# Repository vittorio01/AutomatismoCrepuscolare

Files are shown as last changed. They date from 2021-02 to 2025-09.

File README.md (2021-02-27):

# AutomatismoCrepuscolare
Un automatismo crepuscolare programmabile e intelligente che può essere applicato in molti campi

La scheda funziona con un semplice arduino pro mini.

In questa pagina è presente, oltre a uno schema elettrico del circuito principale e il programma per l'atmega328, anche una guida per l'utilizzo e la costruzione.
Per chi volesse costruire la scheda elettronica, sul file bottom.pdf è predente la faccia inferiore (l'unica) gia pronta per essere utilizzata (da notare che vanno mssi anche due ponticelli.

Questo progetto è ancora in fase sperimentale, quindi c'è la possibilità che non funzioni correttamente.

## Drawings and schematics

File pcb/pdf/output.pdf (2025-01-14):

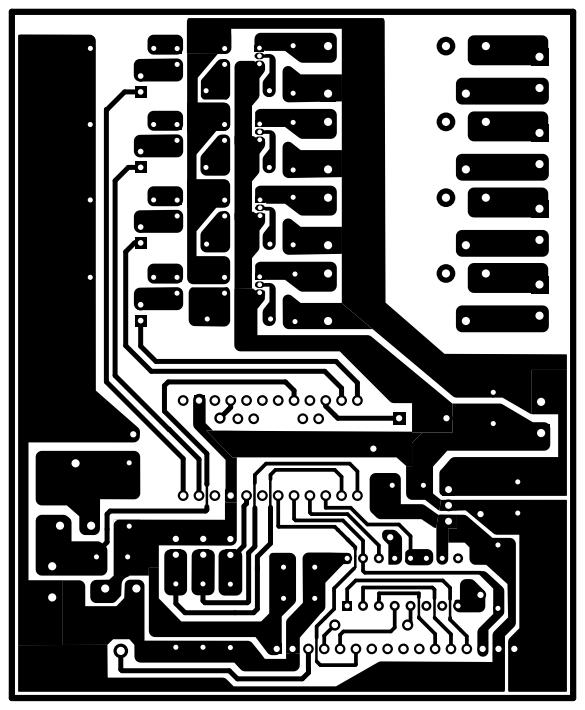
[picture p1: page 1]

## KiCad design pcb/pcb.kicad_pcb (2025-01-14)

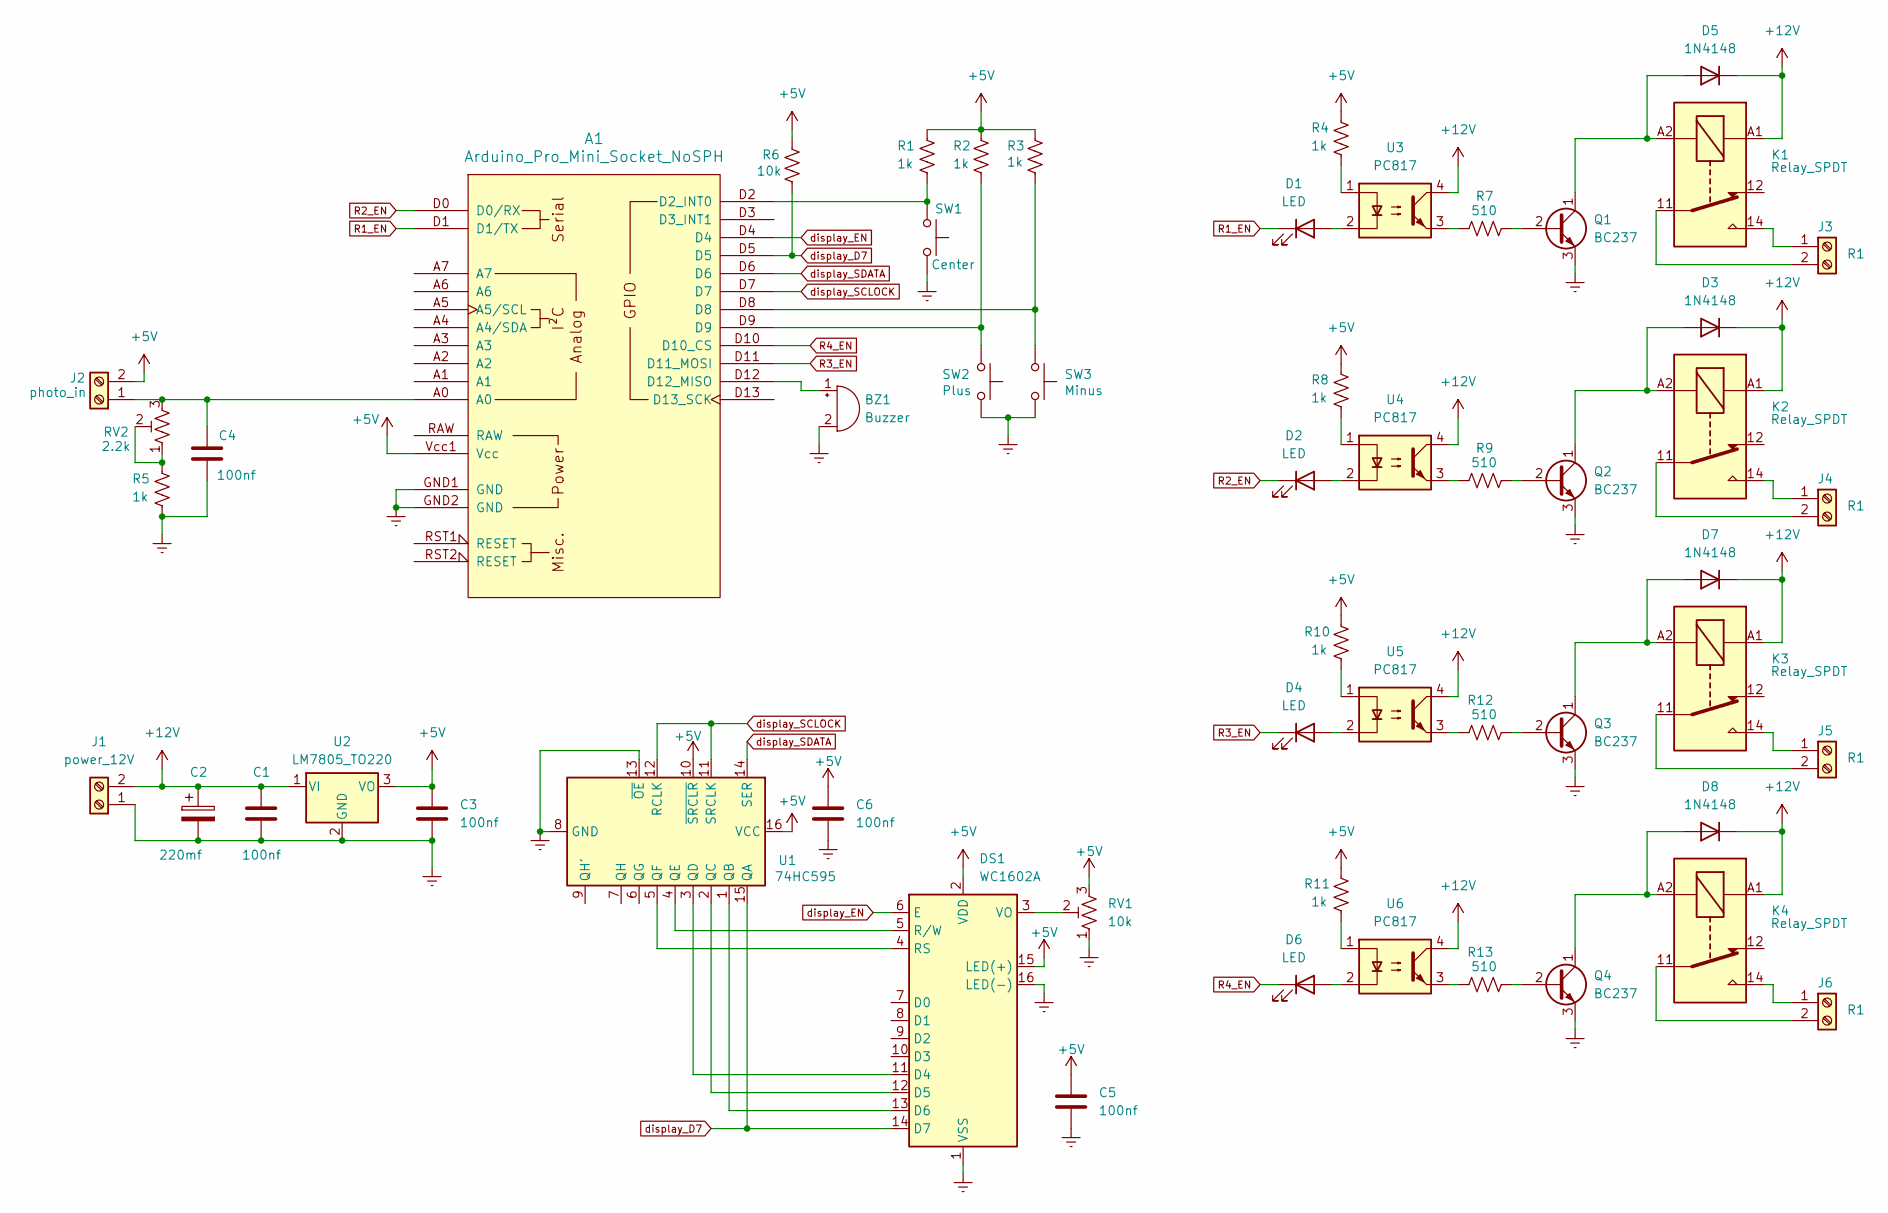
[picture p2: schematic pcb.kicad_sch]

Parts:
A1: Arduino_Pro_Mini_Socket_NoSPH
BZ1: Buzzer; Buzzer_15x7.5RM7.6
C1, C3, C4, C5, C6: 100nf; C_Rect_L7.2mm_W3.5mm_P5.00mm_FKS2_FKP2_MKS2_MKP2
C2: 220mf; C_Radial_D10.0mm_H12.5mm_P5.00mm
D1, D2, D4, D6: LED; LED_D5.0mm
D3, D5, D7, D8: 1N4148; D_DO-35_SOD27_P7.62mm_Horizontal
DS1: WC1602A; PinHeader_1x16_P2.54mm_Vertical
J1: power_12V; TerminalBlock_MaiXu_MX126-5.0-02P_1x02_P5.00mm
J2: photo_in; TerminalBlock_MaiXu_MX126-5.0-02P_1x02_P5.00mm
J3, J4, J5, J6: R1; TerminalBlock_MaiXu_MX126-5.0-02P_1x02_P5.00mm
K1, K2, K3, K4: Relay_SPDT; Relay_1-Form-C_Schrack-RYII_RM3.2mm
Q1, Q2, Q3, Q4: BC237; TO-92_Inline
R1, R2, R3, R4, R5, R8, R10, R11: 1k; R_Axial_DIN0207_L6.3mm_D2.5mm_P10.16mm_Horizontal
R6: 10k; R_Axial_DIN0207_L6.3mm_D2.5mm_P10.16mm_Horizontal
R7, R9, R12, R13: 510; R_Axial_DIN0207_L6.3mm_D2.5mm_P10.16mm_Horizontal
RV1: 10k; Potentiometer_Piher_PT-10-V10_Vertical
RV2: 2.2k; Potentiometer_Piher_PT-10-V10_Vertical
SW1: Center; PinHeader_1x02_P2.54mm_Vertical
SW2: Plus; PinHeader_1x02_P2.54mm_Vertical
SW3: Minus; PinHeader_1x02_P2.54mm_Vertical
U1: 74HC595; DIP-16_W7.62mm_Socket
U2: LM7805_TO220; TO-220-3_Vertical
U3, U4, U5, U6: PC817; DIP-4_W7.62mm

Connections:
+5V: A1.Vcc1 (Vcc), C3.1, C5.1, C6.1, DS1.2 (VDD), DS1.15 (LED(+)), J2.2, R1.1, R2.1, R3.1, R4.1, R6.1, R8.1, R10.1, R11.1, RV1.3, U1.10 (~SRCLR), U1.16 (VCC), U2.3 (VO)
+12V: C1.1, C2.1, D3.1 (K), D5.1 (K), D7.1 (K), D8.1 (K), J1.2, K1.A1, K2.A1, K3.A1, K4.A1, U2.1 (VI), U3.4, U4.4, U5.4, U6.4
GNDREF: A1.GND1 (GND), A1.GND2 (GND), BZ1.2 (-), C1.2, C2.2, C3.2, C4.2, C5.2, C6.2, DS1.1 (VSS), DS1.16 (LED(-)), J1.1, Q1.3 (E), Q2.3 (E), Q3.3 (E), Q4.3 (E), R5.2, RV1.1, SW1.2, SW2.2, SW3.2, U1.8 (GND), U1.13 (~OE), U2.2 (GND)
unnamed: A1.D2 (D2_INT0), R1.2, SW1.1
unnamed: A1.D12 (D12_MISO), BZ1.1 (+)
unnamed: A1.D8, R3.2, SW3.1
unnamed: A1.D9, R2.2, SW2.1
unnamed: D1.2 (A), U3.2
unnamed: D2.2 (A), U4.2
unnamed: D3.2 (A), K2.A2, Q2.1 (C)
unnamed: D4.2 (A), U5.2
unnamed: D5.2 (A), K1.A2, Q1.1 (C)
unnamed: D6.2 (A), U6.2
unnamed: D7.2 (A), K3.A2, Q3.1 (C)
unnamed: D8.2 (A), K4.A2, Q4.1 (C)
unnamed: DS1.11 (D4), U1.3 (QD)
unnamed: DS1.12 (D5), U1.2 (QC)
unnamed: DS1.13 (D6), U1.1 (QB)
unnamed: DS1.4 (RS), U1.5 (QF)
unnamed: DS1.5 (R/W), U1.4 (QE)
unnamed: DS1.3 (VO), RV1.2
unnamed: A1.A0, C4.1, J2.1, RV2.3
unnamed: J3.1, K1.14
unnamed: J3.2, K1.11
unnamed: J4.1, K2.14
unnamed: J4.2, K2.11
unnamed: J5.1, K3.14
unnamed: J5.2, K3.11
unnamed: J6.1, K4.14
unnamed: J6.2, K4.11
unnamed: Q1.2 (B), R7.2
unnamed: Q2.2 (B), R9.2
unnamed: Q3.2 (B), R12.2
unnamed: Q4.2 (B), R13.2
unnamed: R4.2, U3.1
unnamed: R5.1, RV2.1, RV2.2
unnamed: R7.1, U3.3
unnamed: R8.2, U4.1
unnamed: R9.1, U4.3
unnamed: R10.2, U5.1
unnamed: R11.2, U6.1
unnamed: R12.1, U5.3
unnamed: R13.1, U6.3
R1_EN: A1.D1 (D1/TX), D1.1 (K)
R2_EN: A1.D0 (D0/RX), D2.1 (K)
R3_EN: A1.D11 (D11_MOSI), D4.1 (K)
R4_EN: A1.D10 (D10_CS), D6.1 (K)
display_D7: A1.D5, DS1.14 (D7), R6.2, U1.15 (QA)
display_EN: A1.D4, DS1.6 (E)
display_SCLOCK: A1.D7, U1.11 (SRCLK), U1.12 (RCLK)
display_SDATA: A1.D6, U1.14 (SER)

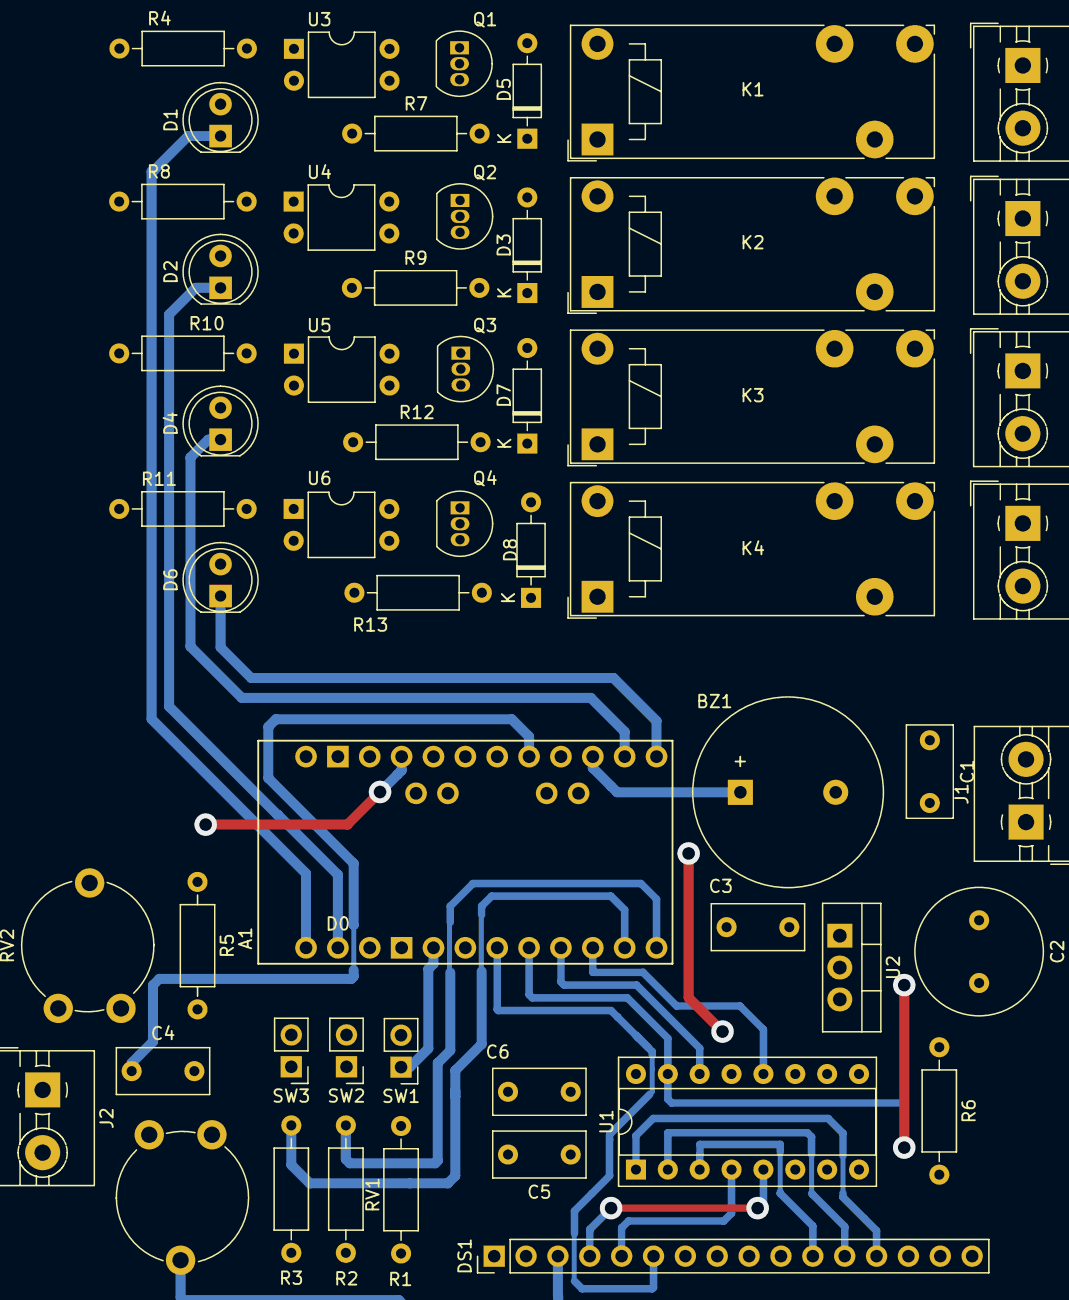
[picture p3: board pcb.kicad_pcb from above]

Board: 2 copper layers, 55 parts (0 on the bottom side), 51 nets.

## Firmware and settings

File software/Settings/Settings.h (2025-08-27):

#ifndef __SETTINGS_H__
#define __SETTINGS_H__

#include "Arduino.h"
#include <EEPROM.h>

#define SETTINGS_CHECK_CHAR 0xAB
#define DEFAULT_POWER1      0
#define DEFAULT_POWER2      0
#define DEFAULT_POWER3      0
#define DEFAULT_POWER4      0
#define DEFAULT_TIMEROFF    10
#define DEFAULT_TIMERON     10
#define DEFAULT_BUZZER      true 

using namespace std;

typedef struct SettingsValues{
    char errorCheck;
    unsigned int power1;
    unsigned int power2;
    unsigned int power3;
    unsigned int power4;

    unsigned int defaultTimerOff;
    unsigned int defaultTimerOn;

    bool buzzer;
} SettingsValues;

class Settings {
    private: 
    SettingsValues values;

    public:
    Settings();
    
    void loadDefault();
    bool loadSaved(unsigned int address);
    void store(unsigned int address);

    void setPower1(unsigned int value);
    void setPower2(unsigned int value);
    void setPower3(unsigned int value);
    void setPower4(unsigned int value);
    void setTimerOn(unsigned int value);
    void setTimerOff(unsigned int value);
    void setBuzzer(bool value);
};


#endif 

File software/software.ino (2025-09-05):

#include "Display.h"
#include "Settings.h"
#include "Sensor.h"
#include "Relays.h"

#include <TimerOne.h>

#define LCD_SHIFT_EN              4
#define LCD_SHIFT_D7              5
#define LCD_SHIFT_SER             6
#define LCD_SHIFT_CLK             7

#define LCD_FORMAT_ROWS           2
#define LCD_FORMAT_COLS           20
#define LCD_MAX_COLS              38
#define SETTINGS_ADDRESS          0

#define PHOTO_PIN                 A0
#define PHOTO_BASEVALUE           0
#define PHOTO_INCREMENT           10

#define SELECT_BUTTON             2
#define MINUS_BUTTON              8
#define PLUS_BUTTON               9

#define RELAY1_PIN                0
#define RELAY2_PIN                1
#define RELAY3_PIN                11  
#define RELAY4_PIN                10

#define BUZZER_PIN                12
#define BUZZER_FREQUENCY          3500

#define DISPLAY_REFRESH_RATE      100000
#define BUTTON_RESOLUTION         200

#define BUTTON_PRESSED_TONE       200
#define ALARM_TONE                5000

typedef enum {CONTROL,MINUS,PLUS,NONE} button;
typedef enum {
  GENERAL,
  SETTINGS_POWER,
  SETTINGS_MASK,
  SETTINGS_TIMERON,
  SETTINGS_TIMEROFF,
  SETTINGS_BUZZER
} view;

Display* screen;
Settings* options;
Sensor* light;
Relays* counters;

void update();

view currentView;
bool blinkStatus;
unsigned int secondCounter;
unsigned int buttonCounter;
unsigned short currentSubView;
button pressedButton;

void setup() {
  noInterrupts(); 

  pinMode(SELECT_BUTTON, INPUT);
  pinMode(MINUS_BUTTON, INPUT);
  pinMode(PLUS_BUTTON, INPUT);
  pinMode(PHOTO_PIN, INPUT);
  pinMode(RELAY1_PIN, OUTPUT);
  pinMode(RELAY2_PIN, OUTPUT);
  pinMode(RELAY3_PIN, OUTPUT);
  pinMode(RELAY4_PIN, OUTPUT);
  pinMode(BUZZER_PIN, OUTPUT);

  digitalWrite(RELAY1_PIN, true);
  digitalWrite(RELAY2_PIN, true);
  digitalWrite(RELAY3_PIN, true);
  digitalWrite(RELAY4_PIN, true);

  currentView=GENERAL;
  blinkStatus=false;
  secondCounter=1000000/DISPLAY_REFRESH_RATE;
  buttonCounter=BUTTON_RESOLUTION/DISPLAY_REFRESH_RATE;
  pressedButton=NONE;

  screen=new Display(LCD_SHIFT_EN, LCD_SHIFT_D7, LCD_SHIFT_SER, LCD_SHIFT_CLK,LCD_FORMAT_ROWS,LCD_FORMAT_COLS,LCD_MAX_COLS);
  options=new Settings();
  light=new Sensor(PHOTO_PIN,PHOTO_BASEVALUE,PHOTO_INCREMENT);
  counters=new Relays(4);
  
  options->loadSaved(SETTINGS_ADDRESS);

  Timer1.initialize((DISPLAY_REFRESH_RATE/2));
  Timer1.attachInterrupt(update);
  interrupts(); 
}

void loop() {}

void update() {
  unsigned int currentPower=light->getCurrentPower();
  
  if (secondCounter>0) {
    secondCounter--;
  } else {
    secondCounter=1000000/DISPLAY_REFRESH_RATE;
    blinkStatus=!blinkStatus;
    counters->updateStatus();

    int leftPower=currentPower;
    bool changes=false;
    for (int l=0;l<LOADS_NUMBER;l++) {
      if (!options->getMask(l)) {
        leftPower-=options->getPower(l);
        switch (counters->getDirection(l)) {
          case STOP:
            if (leftPower>0) counters->setCount(l,0,ON);
          break;
          case START:
            if (leftPower<0) counters->setCount(l,0,OFF);
          break;
          case ON:
            if (leftPower<0) counters->setCount(l,options->getTimerOff(),STOP);
            changes=changes || counters->getChanged(l);
          break;
          case OFF:
            if (leftPower>0) counters->setCount(l,options->getTimerOn(),START);
            changes=changes || counters->getChanged(l);
          break;
        }
      } else {
        counters->setCount(l,0,OFF);
      }
      counters->clearFlag(l);
    }

    if (counters->getDirection(0)==START || counters->getDirection(0)==OFF) digitalWrite(RELAY1_PIN,true);
    else digitalWrite(RELAY1_PIN,false);
    if (counters->getDirection(1)==START || counters->getDirection(1)==OFF) digitalWrite(RELAY2_PIN,true);
    else digitalWrite(RELAY2_PIN,false);
    if (counters->getDirection(2)==START || counters->getDirection(2)==OFF) digitalWrite(RELAY3_PIN,true);
    else digitalWrite(RELAY3_PIN,false);
    if (counters->getDirection(3)==START || counters->getDirection(3)==OFF) digitalWrite(RELAY4_PIN,true);
    else digitalWrite(RELAY4_PIN,false);

  }

  button detectedButton=NONE;
  if (!digitalRead(PLUS_BUTTON)) detectedButton=PLUS;
  if (!digitalRead(MINUS_BUTTON)) detectedButton=MINUS;
  if (!digitalRead(SELECT_BUTTON)) detectedButton=CONTROL;
  if (detectedButton==pressedButton) {
    if (buttonCounter>0) buttonCounter--;
    else {
      buttonCounter=BUTTON_RESOLUTION/DISPLAY_REFRESH_RATE;
      pressedButton=detectedButton;
    }
  }
  
  switch (currentView) {
    case GENERAL:
      if (pressedButton==PLUS) currentSubView++;
      if (pressedButton==CONTROL) {
        currentView=SETTINGS_POWER;
      }
      if (currentSubView==0) {
        screen->write(0,0,"Potenza:  ");
        screen->write(0,10,String(currentPower)+"W    ");
        for (unsigned int l=0;l<LOADS_NUMBER ;l++) {
          switch (counters->getDirection(l)) {
            case ON:
              screen->write(1,(l*5),"ON   ");
            break;
            case OFF:
              screen->write(1,(l*5),"OFF  ");
            break;
            case STOP:
              screen->write(1,(l*5),"ON   ");
              if(blinkStatus) {
                screen->write(1,2+(l*5),String((char) 0b00011111));
              } else {
                screen->write(1,2+(l*5),String("  "));
              }
            break;
            case START:
              if(blinkStatus) {
                screen->write(1,3+(l*5),String((char) 0b00011110));
              } else {
                screen->write(1,3+(l*5),String("  "));
              }
            break;
          }
        }

      } else {
        if (currentSubView>=LOADS_NUMBER) {
          currentSubView=0;
          currentView=GENERAL;
        } else {
          screen->write(0,0,"Porta "+String(currentSubView)+":            ");
          switch(counters->getDirection(0)) {
            case ON:
              screen->write(0,10,"ON ");
              break;
            case STOP:
              screen->write(0,10,"ON ");
              screen->write(1,0,"Spegnimento in "+String(counters->getCount(currentSubView-1))+"    ");
            break;
            
            case OFF:
              screen->write(0,10,"OFF");
              if (options->getMask(currentSubView-1)) {
                screen->write(1,0,"Mascherato          ");
              } else {
                screen->write(1,0,"                    ");
              }
              break;
            case START:
              screen->write(0,10,"OFF");
              screen->write(1,0,"Accensione in "+String(counters->getCount(currentSubView-1))+"    ");
            break;
          }
        }
      }
    break;
    case SETTINGS_MASK:
      switch (pressedButton) {
        case PLUS:
          if (currentSubView==0) currentSubView=1;
          else if (currentSubView<LOADS_NUMBER) options->setMask((currentSubView-1),true);
        break;

        case MINUS:
          if (currentSubView==0) currentSubView=1;
          else if (currentSubView<LOADS_NUMBER) options->setMask((currentSubView-1),false);
        break;

        case CONTROL:
          if (currentSubView>0) {
            if (currentSubView>=LOADS_NUMBER) {
              currentSubView=0;
              currentView=SETTINGS_TIMERON;
            }
            else {
              currentSubView++;
            }
          } else {
            currentSubView=0;
            currentView=SETTINGS_TIMERON;
          }
        break;
      }
      if (currentSubView==0) {
        screen->clear();
        screen->write(0,0,"Maschere");
      } else {
        screen->write(0,0,"Maschera carico "+String(currentSubView)+"     ");
        screen->write(1,0,String((char) 0b00111110)+" ");
        if (options->getMask(currentSubView-1)) {
          screen->write(1,2,String("ON "));
        } else {
          screen->write(1,2,String("OFF "));
        }
        
      }
    break;

    case SETTINGS_POWER:
      switch (pressedButton) {
        case PLUS:
          if (currentSubView==0) currentSubView=1;
          else if (currentSubView<LOADS_NUMBER) options->setPower((currentSubView-1),options->getPower(currentSubView-1)+1);
        break;

        case MINUS:
          if (currentSubView==0) currentSubView=1;
          else if (currentSubView<LOADS_NUMBER) options->setPower((currentSubView-1),options->getPower(currentSubView-1)-1);
        break;

        case CONTROL:
          if (currentSubView>0) {
            if (currentSubView>=LOADS_NUMBER) {
              currentSubView=0;
              currentView=SETTINGS_MASK;
            }
            else {
              currentSubView++;
            }
          } else {
            currentSubView=0;
            currentView=SETTINGS_MASK;
          }
        break;
      }
      if (currentSubView==0) {
        screen->clear();
        screen->write(0,0,"Potenza carichi     ");
      } else {
        screen->write(0,0,"Potenza carico "+String(currentSubView)+"     ");
        screen->write(1,0,String((char) 0b00111110)+" ");
        screen->write(1,2,String(options->getPower(currentSubView-1))+"    ");
      }
    break;

    case SETTINGS_TIMERON:
      switch (pressedButton) {
        case PLUS:
          options->setTimerOn(options->getTimerOn()+1);
        break;

        case MINUS:
          options->setTimerOn(options->getTimerOn()-1);
        break;

        case CONTROL:
          currentView=SETTINGS_TIMEROFF;
        break;
      }
      screen->clear();
      screen->write(0,0,"Timer allaccio ");
      screen->write(1,0,String((char) 0b00111110)+" ");
      screen->write(1,2,String(options->getTimerOn())+"    ");
    
    break;

    case SETTINGS_TIMEROFF:
      switch (pressedButton) {
        case PLUS:
          options->setTimerOff(options->getTimerOff()+1);
        break;

        case MINUS:
          options->setTimerOff(options->getTimerOff()-1);
        break;

        case CONTROL:
          currentView=SETTINGS_TIMEROFF;
        break;
      }
      screen->clear();
      screen->write(0,0,"Timer distacco ");
      screen->write(1,0,String((char) 0b00111110)+" ");
      screen->write(1,2,String(options->getTimerOff())+"    ");
    
    break;

    case SETTINGS_BUZZER:
      switch (pressedButton) {
        case PLUS:
          options->setBuzzer(true);
        break;

        case MINUS:
          options->setBuzzer(false);
        break;

        case CONTROL:
          Timer1.stop();
          screen->clear();
          delay(2000);
          currentView=GENERAL;
          currentSubView=0;
          options->store(SETTINGS_ADDRESS);
          Timer1.start();
        break;
      }
      screen->clear();
      screen->write(0,0,"Avvisi sonori ");
      screen->write(1,0,String((char) 0b00111110)+" ");
      if (options->getBuzzer()) {
        screen->write(1,2,"OFF    ");
      } else {
        screen->write(1,2,"ON     ");
      }
    
    break;

    default:
      currentView=GENERAL;
    break;
  }
  screen->update();
}

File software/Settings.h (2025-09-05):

#ifndef __SETTINGS_H__
#define __SETTINGS_H__

#include "Arduino.h"
#include <EEPROM.h>

#define SETTINGS_CHECK_CHAR 0xAB
#define DEFAULT_POWER       0
#define LOADS_NUMBER        4
#define DEFAULT_TIMEROFF    10
#define DEFAULT_TIMERON     10
#define DEFAULT_BUZZER      true 

#define MAX_SETTINGS_BOUND  65536

using namespace std;

typedef struct SettingsValues{
    char errorCheck;
    unsigned int powers[LOADS_NUMBER];
    bool masks[LOADS_NUMBER];

    unsigned int defaultTimerOff;
    unsigned int defaultTimerOn;

    bool buzzer;
} SettingsValues;

class Settings {
    private: 
    SettingsValues values;

    public:
    Settings();
    
    void loadDefault();
    bool loadSaved(unsigned int address);
    void store(unsigned int address);

    void setPower(unsigned int load, unsigned int value);
    void setTimerOn(unsigned int value);
    void setTimerOff(unsigned int value);
    void setBuzzer(bool value);
    void setMask(unsigned int load, bool value);
    

    unsigned int getPower(unsigned int load);
    unsigned int getTimerOn();
    unsigned int getTimerOff();
    bool getBuzzer();
    bool getMask(unsigned int load);

};


#endif 
